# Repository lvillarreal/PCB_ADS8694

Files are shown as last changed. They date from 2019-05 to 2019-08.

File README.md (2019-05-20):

# PCB PARA ADS8694

## Características del PCB

 - 4 entradas diferenciales con acondiconamiento (AD8221)
 - Entrada canal 0 sin filtro RC
 - Entradas canales 1-3 con filtro RC, LP 
 - Salida compatible con Pmod (6x6, 2.54mm, 90º) de Xilinx
 - Uso de referencia interna de AD

## Características ADS8694

 - 18 bits
 - 500 kSPS
 - Filtro Pasa bajos incorporado internamente, fc=15 kHz (Oversampling)
 - Interface SPI
 - Pin de alarma
 - Impedancia de entrada: 1MΩ
 - Encapsulado TSSOP (38)
 - Conversión SAR (aproximaciones sucesivas)

### Diagrama en bloques

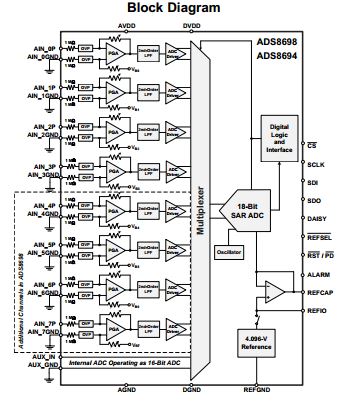
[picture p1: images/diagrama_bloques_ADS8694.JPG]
Diagrama en bloques


### Pines

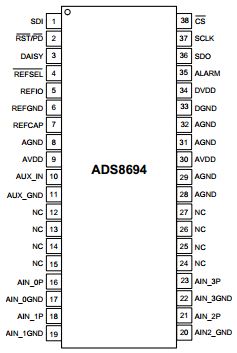
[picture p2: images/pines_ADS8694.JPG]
Pinout


### Definicion de Pines

| Nº | Nombre | I/O | Descripción |
| -- | -----| --- | --- |
| 1  | SDI  |Entrada Digital | Data in |
| 2  | /RST-/PD | Entrada Digital  | Reset y Power Down |
| 3  | DAISY  | Entrada Digital | Modo Daisy-Chain |
| 4  | /REFSEL  |Entrada Digital  | Entrada lógica activa por bajo para habilitar la referencia interna. Cuando está en bajo, la referencia interna está habilitada.  REFIO se convierte en una salida que incluye la referencia de tensión V_REF. Cuando REFSEL está en alto la ref interna está deshabilitada y REFIO se convierte en la referencia (entrada analógica)|
| 5  | REFIO  | Entrada/Salida Analógica  | Se explica arriba |
| 6  | REFGND  | Power Supply | Pin de GND analógica, corto al plano analógico GND. Desacoplar con REFIO en el pin 5 y REFCAP en el pin 7 |
| 7  | REFCAP  | Salida Analógica | Pin de condensador de desacoplamiento de referencia ADC. Desacoplar con REFGND en el pin 6 |
| 8 |  AGND | Power Supply | Pin de tierra analógica. Desacoplar con AVDD en pin 9 |
| 9  |  AVDD |  Power Supply  | Pin suministro analógico. Desacoplar con AGND pin 8|
| 10 | AUX_IN | Entrada Analógica | Canal de entrada auxiliar: entrada positiva. Desacoplar con pin 11, AUX_GND |
| 11 | AUX_GND | Entrada Analógica | Canal de entrada auxiliar: entrada negativa. Desacoplar con pin 10, AUX_IN |
|16|AIN_0P| Entrada analógica |Canal de entrada analógica 0, entrada positiva. Desacoplar con AIN_0GND en el pin 17|
|17| AIN_0GND| Entrada analógica| Canal de entrada analógica 0, entrada negativa. Desacoplar con AIN_0P en el pin 16|
| 18 | AIN_1P | Entrada analógica |  |
| 19 |AIN_1GND | Entrada analógica |  |
| 20 | AIN_2GND | Entrada analógica |  |
| 21 | AIN_2P | Entrada analógica |  |
| 22 | AIN_3GND | Entrada analógica |  |
| 23 | AIN_3P | Entrada analógica |  |
|28| AGND| Power Supply| Toma de tierra analógica|
|29| AGND| Power Supply| Toma de tierra analógica|
|30| AVDD| Power Supply| Fuente de alimentación analógica. Desacoplar con AGND
|31| AGND| Power Supply| Toma de tierra analógica|
|32| AGND| Power Supply|
|33| DGND | Power Supply | Desacoplar con 35, DVDD|
|34| AVDD | Power Supply | Desacoplar con 34, AGND|
|35|ALARM| Salida Digital |Salida de alarma activa por alto|
|36|SDO| Salida Digital | Dato de salida, SPI|
|37|SCL| Entrada Digital | clock SPI |
|38|/CS| Entrada digital | Chip Slect SPI, activo por bajo|

### Entrada Analógica

El rango de tensión de entrada se puede configurar para ±2.5 Vref, ±1.25 Vref ; ±0.625 Vref (bipolar) o 0 a 2.5 Vref, 0 a 1.25 Vref (unipolar). La configuración es independiente para cada canal (4 canales).
El dispositivo muestrea la diferencia entre AIN_nP y AIN_nGND, donde el valor máximo que puede tomar AIN_nGND es ±0.1 V.

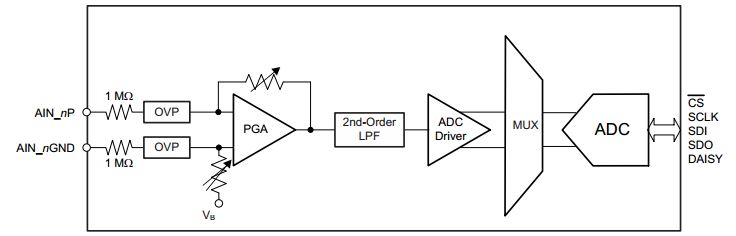
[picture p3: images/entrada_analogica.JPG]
Entrada_Analógica


### Programmable Gain Amplifier (PGA)

Dependiendo del rango de la señal de entada, se puede ajustar la ganancia modificando los bits Range_CHn [3:0] en el registro de programa.El valor predeterminado es 0000, que corresponde a un rango de señal de entrada de ± 2.5 × Vref.

| Rango de entrada analógica | Bit 3 | Bit 2 | Bit 1 | Bit 0 |
|---|---|---|---|---|
| ±2.5 x Vref | 0 | 0 | 0 | 0 |
| ±1.25 x Vref | 0 | 0 | 0 | 1 |
| ±0.625 x Vref | 0 | 0 | 1 | 0 |
|0 a 2.5 x Vref | 0 | 1 | 0 | 1 |
|0 a 1.25 x Vref | 0 | 1 | 1 | 0 |

### Multiplexor

Dispone de un mux analógico de 4 canales. Puede funcionar en modo manual o de escaneo automático.En modo manual (MAN_Ch_n), el canal se selecciona para cada muestra a través de un registro de escritura; en modo de escaneo automático (AUTO_RST), el número de canal se incrementa automáticamente en cada flanco descendente de /CS después de muestrear el canal actual.
Las entradas analógicas pueden ser seleccionadas por un scaneo automático configurando los registros pertinente. El dispositivo escanea solo las entradas analógicas seleccionadas en orden ascendente. El rendimiento total es de 500kSPS, pero se divide entre los canales activos. Si hay uno solo activo, será de 500 kSPS; si hay 2 será de 250kSPS por canal; etc.

### Referencia interna
Circuito recomendado

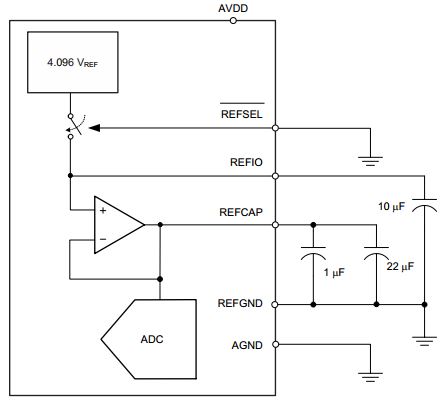
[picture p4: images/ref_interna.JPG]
Referencia interna


### Modos de funcionamiento
El ADS8694 admite múltiples modos de operación que son programables por software. Después de encendido, el dispositivo se coloca en modo inactivo y no realiza ninguna función hasta que se recibe un comando del usuario. Más adelante se enumeran en una tabla todos los comandos para ingresar a los diferentes modos del dispositivo. Después del encendido, los registros de programa se activan con los valores predeterminados y requieren ajustes de configuración apropiados antes de realizar cualquier conversión. El siguiente diagrama explica cómo cambiar el dispositivo de un modo de operación a otro.

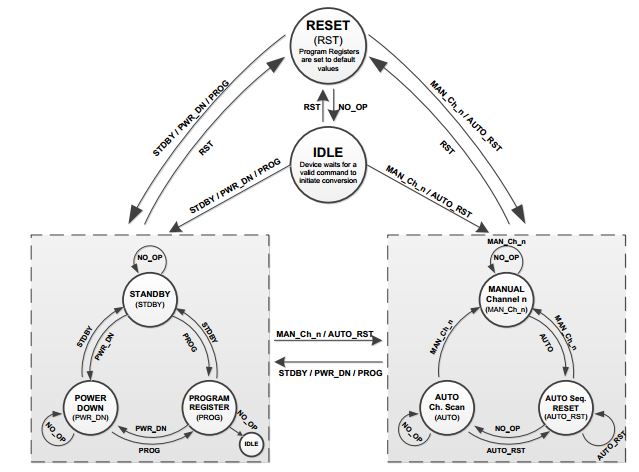
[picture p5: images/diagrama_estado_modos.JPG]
Modos de operacion


### Valores de LSB para Vref de 4.096 V

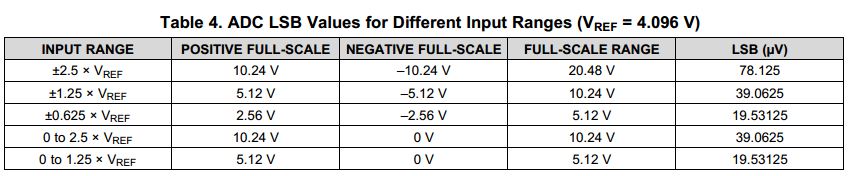
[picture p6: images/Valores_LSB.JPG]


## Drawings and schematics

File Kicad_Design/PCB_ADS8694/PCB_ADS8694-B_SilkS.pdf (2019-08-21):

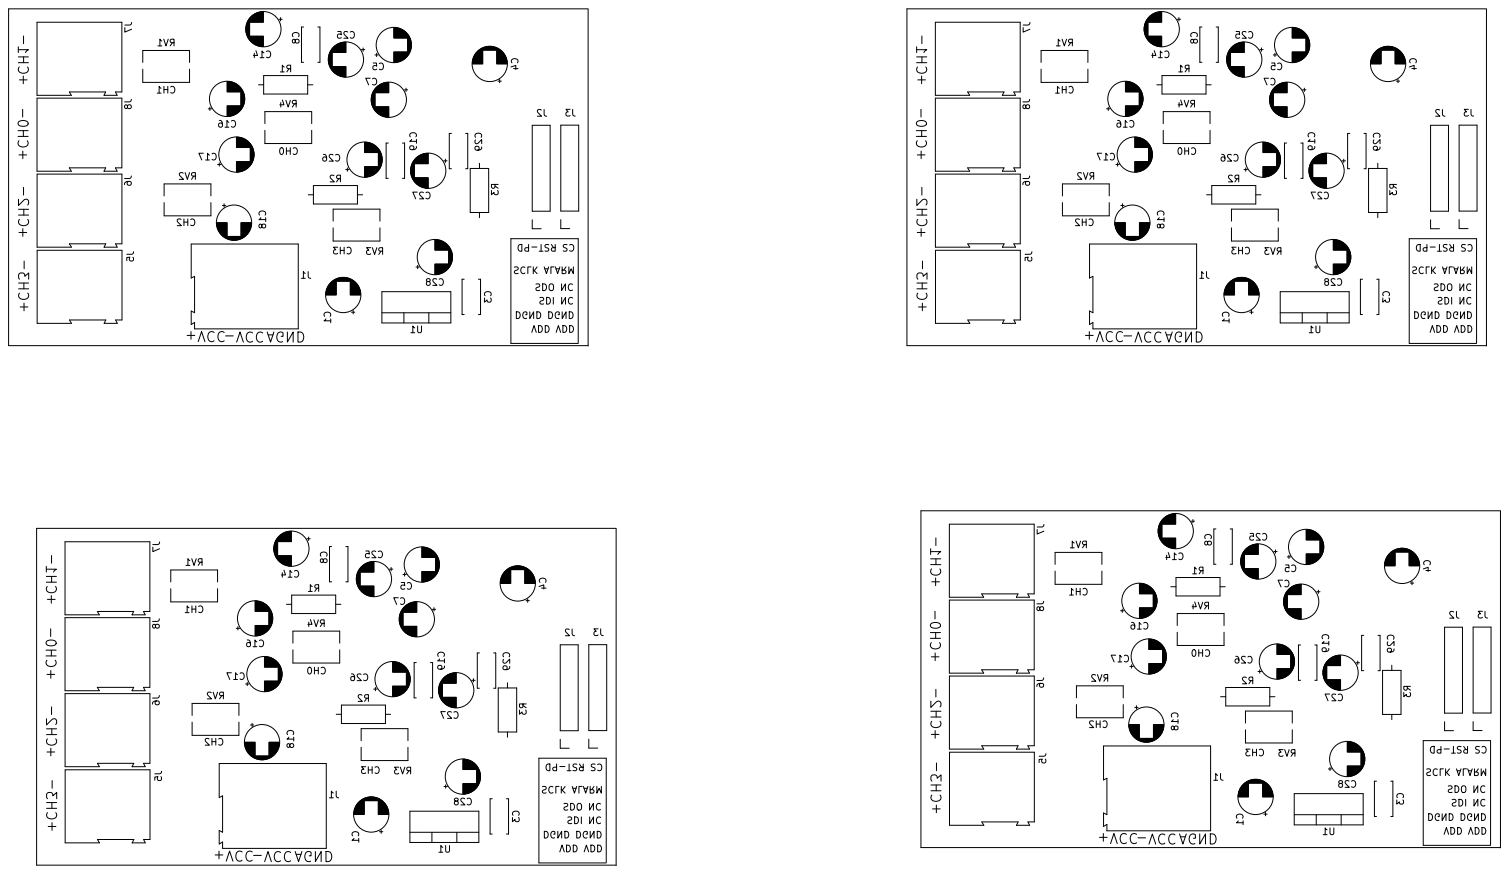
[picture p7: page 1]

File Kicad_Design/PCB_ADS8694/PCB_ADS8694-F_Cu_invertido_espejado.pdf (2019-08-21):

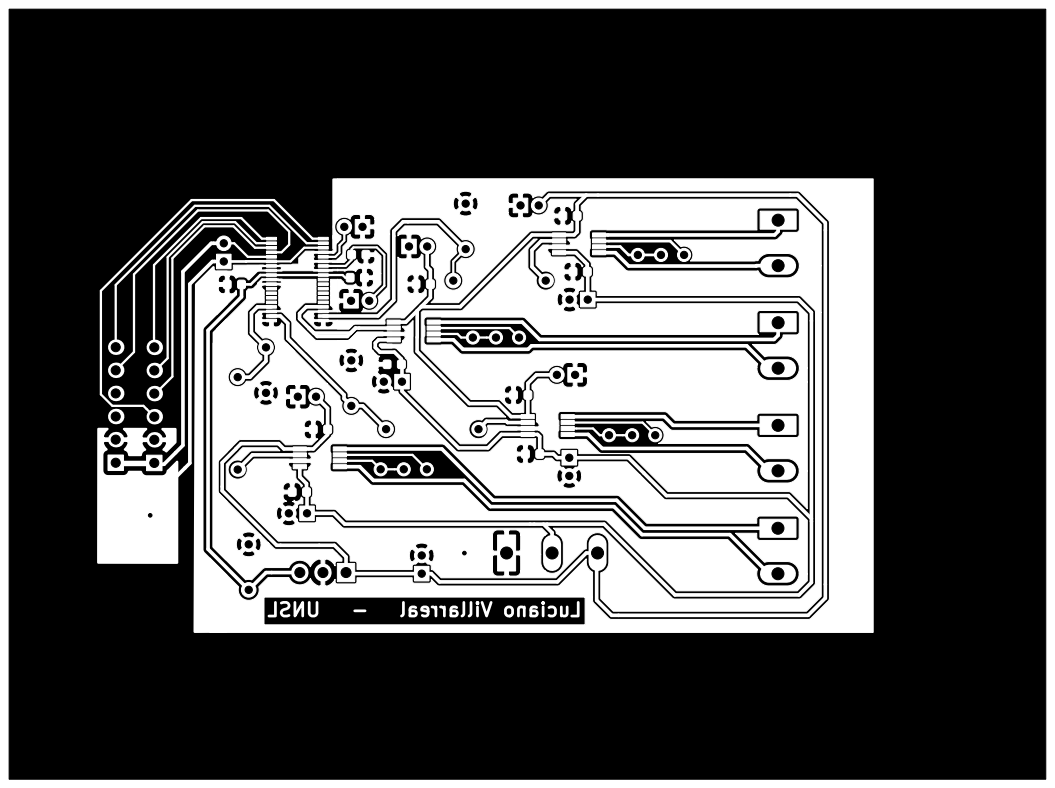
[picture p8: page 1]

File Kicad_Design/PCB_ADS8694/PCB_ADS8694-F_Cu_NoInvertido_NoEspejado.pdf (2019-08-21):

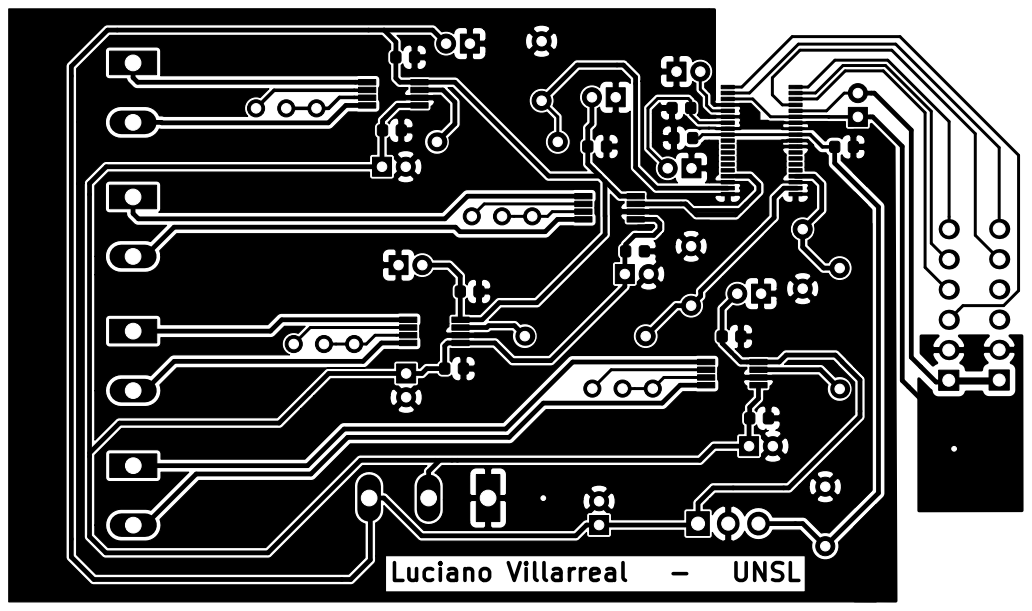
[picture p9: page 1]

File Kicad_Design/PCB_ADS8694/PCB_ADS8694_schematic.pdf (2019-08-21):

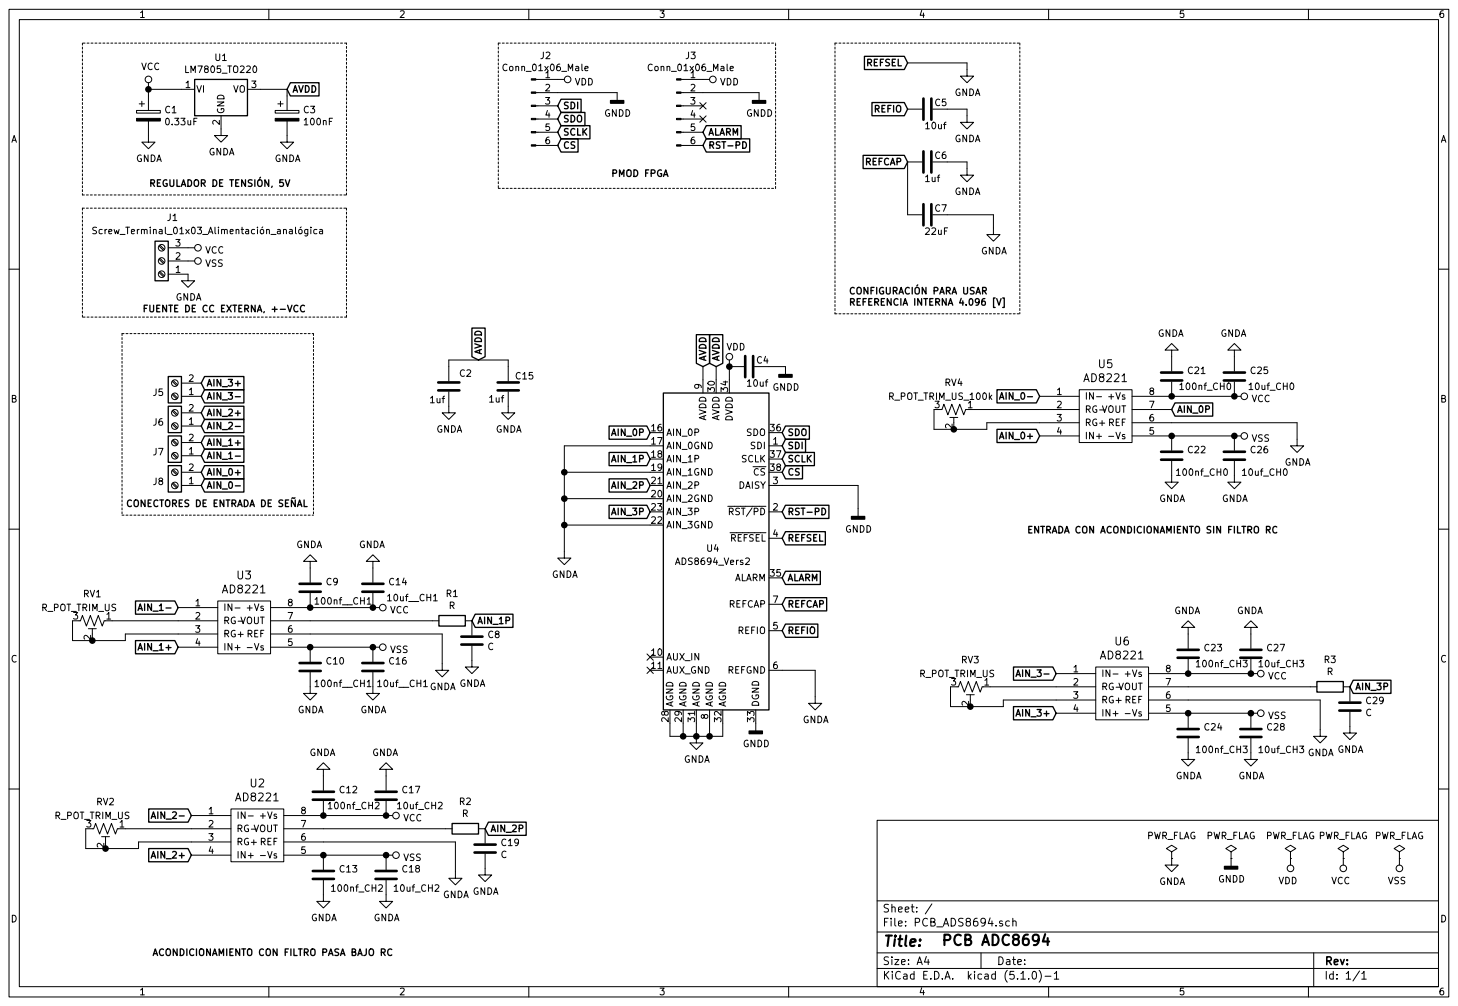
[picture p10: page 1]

REFERENCIA INTERNA 4.096 [V] PMOD FPGA

REFCAP CONFIGURACIÓN PARA USAR

ENTRADA CON ACONDICIONAMIENTO SIN FILTRO RC

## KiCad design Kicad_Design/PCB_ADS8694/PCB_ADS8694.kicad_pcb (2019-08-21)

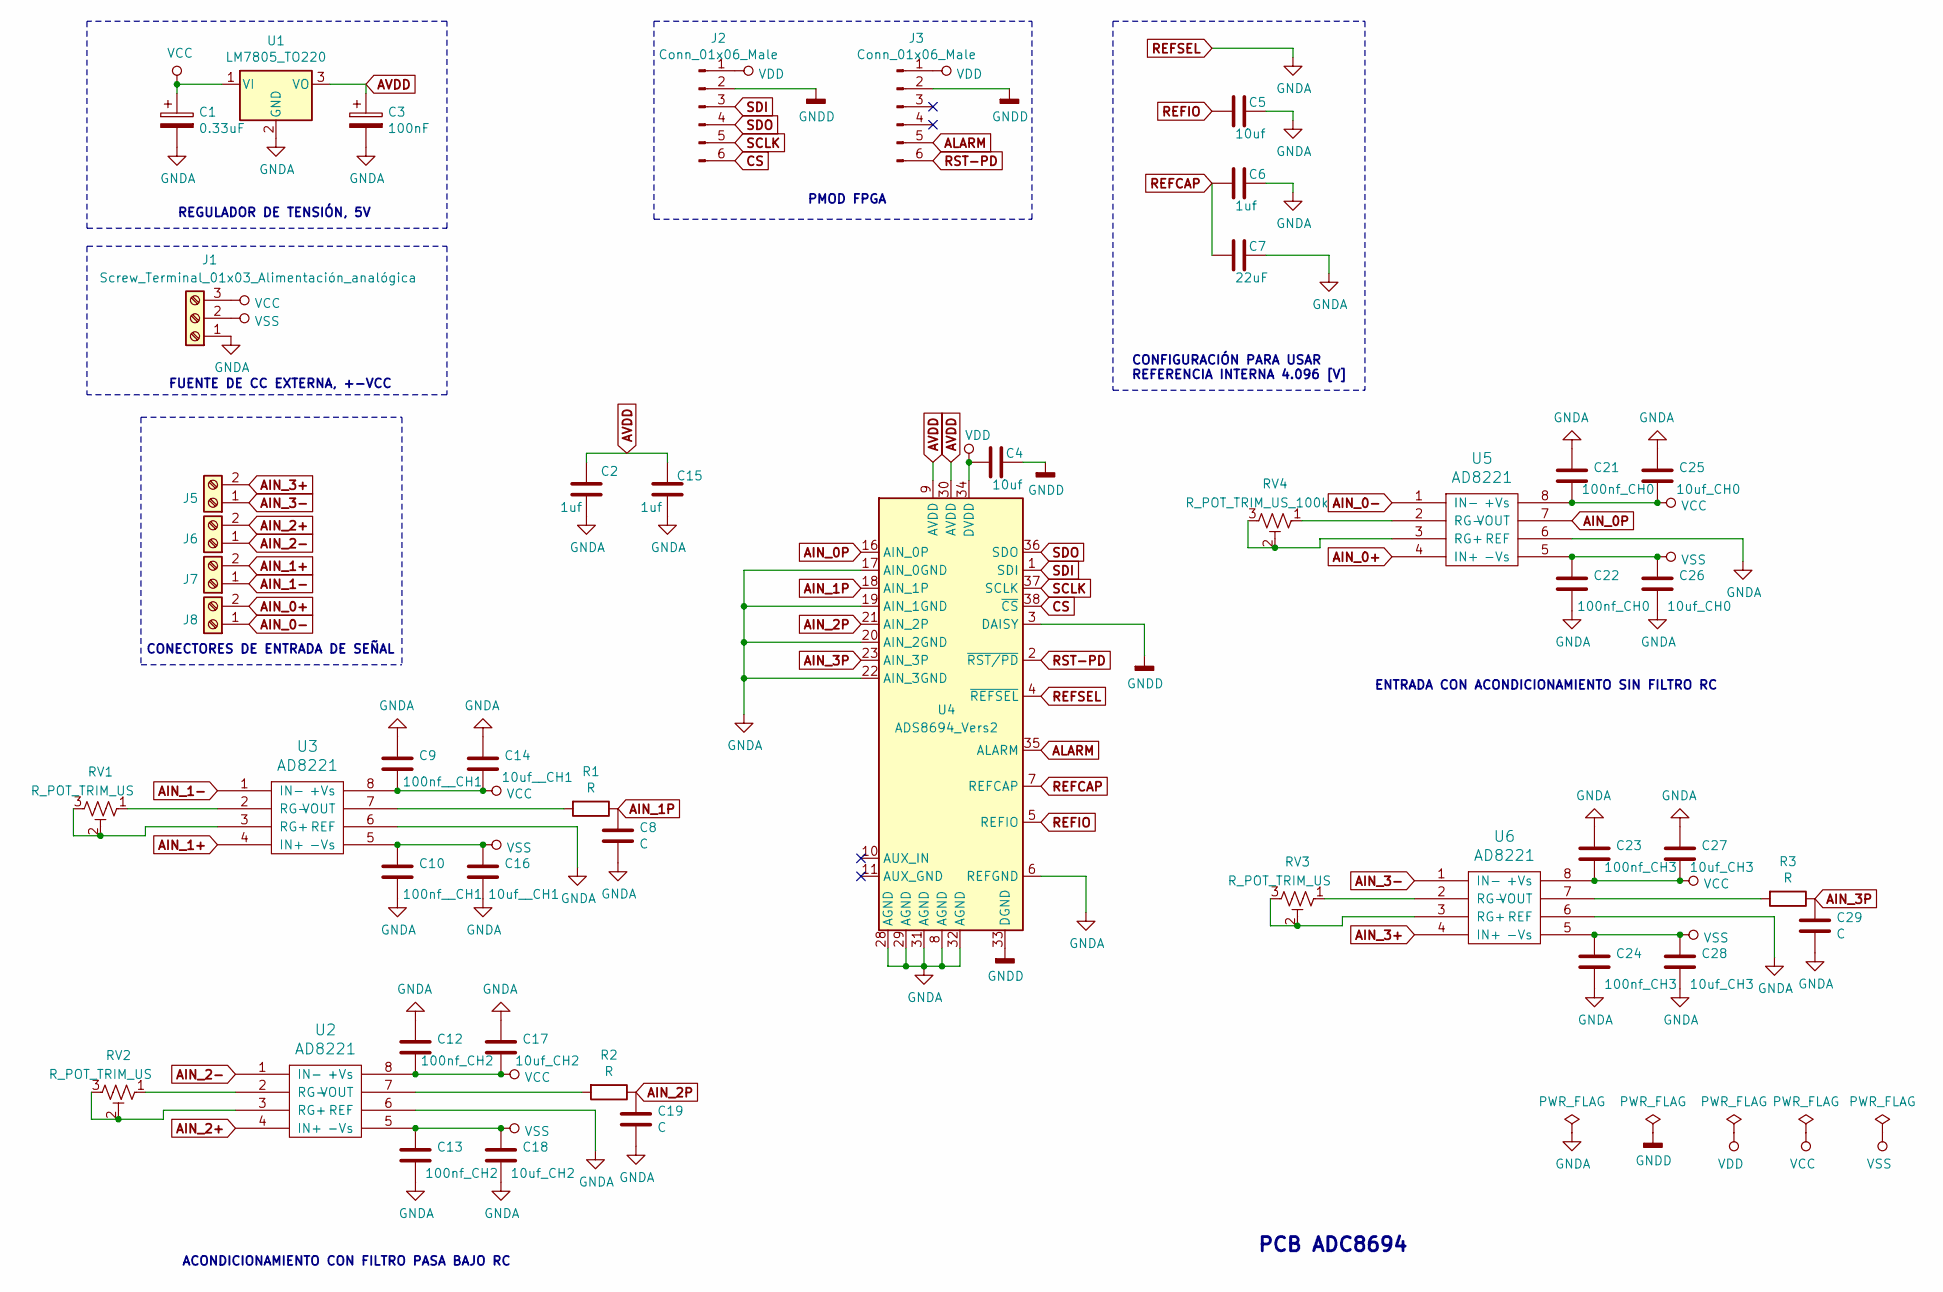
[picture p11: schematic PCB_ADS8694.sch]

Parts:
C1: 0.33uF; CP_Radial_D5.0mm_P2.00mm
C2, C6, C15: 1uf; C_0603_1608Metric
C3: 100nF; C_Disc_D5.0mm_W2.5mm_P5.00mm
C4, C5: 10uf; CP_Radial_D5.0mm_P2.00mm
C7: 22uF; CP_Radial_D5.0mm_P2.00mm
C8, C19, C29: C; C_Disc_D5.0mm_W2.5mm_P5.00mm
C9, C10: 100nf__CH1; C_0603_1608Metric
C12, C13: 100nf_CH2; C_0603_1608Metric
C14, C16: 10uf__CH1; CP_Radial_D5.0mm_P2.00mm
C17, C18: 10uf_CH2; CP_Radial_D5.0mm_P2.00mm
C21, C22: 100nf_CH0; C_0603_1608Metric
C23, C24: 100nf_CH3; C_0603_1608Metric
C25, C26: 10uf_CH0; CP_Radial_D5.0mm_P2.00mm
C27, C28: 10uf_CH3; CP_Radial_D5.0mm_P2.00mm
J1: Screw_Terminal_01x03_Alimentación_analógica; TerminalBlock_Altech_AK300-3_P5.00mm
J2, J3: Conn_01x06_Male; PinHeader_1x06_P2.54mm_Vertical
J5: Screw_Terminal_01x02_CH3; TerminalBlock_Altech_AK300-2_P5.00mm
J6: Screw_Terminal_01x02_CH2; TerminalBlock_Altech_AK300-2_P5.00mm
J7: Screw_Terminal_01x02_CH1; TerminalBlock_Altech_AK300-2_P5.00mm
J8: Screw_Terminal_01x02_CH0; TerminalBlock_Altech_AK300-2_P5.00mm
R1, R2, R3: R; R_Axial_DIN0207_L6.3mm_D2.5mm_P10.16mm_Horizontal
RV1, RV2, RV3: R_POT_TRIM_US; Potentiometer_Bourns_3266Y_Vertical
RV4: R_POT_TRIM_US_100k; Potentiometer_Bourns_3266Y_Vertical
U1: LM7805_TO220; TO-220-3_Vertical
U2, U3, U5, U6: AD8221; MSOP-8_3x3mm_P0.65mm
U4: ADS8694_Vers2; TSSOP-38_4.4x9.7mm_P0.5mm

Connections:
AIN_0+: J8.2, U5.4 (IN+)
AIN_0-: J8.1, U5.1 (IN-)
AIN_0P: U4.16 (AIN_0P), U5.7 (VOUT)
AIN_1+: J7.2, U3.4 (IN+)
AIN_1-: J7.1, U3.1 (IN-)
AIN_1P: C8.1, R1.1, U4.18 (AIN_1P)
AIN_2+: J6.2, U2.4 (IN+)
AIN_2-: J6.1, U2.1 (IN-)
AIN_2P: C19.1, R2.1, U4.21 (AIN_2P)
AIN_3+: J5.2, U6.4 (IN+)
AIN_3-: J5.1, U6.1 (IN-)
AIN_3P: C29.1, R3.1, U4.23 (AIN_3P)
ALARM: J3.5, U4.35 (ALARM)
AVDD: C2.1, C3.1, C15.2, U1.3 (VO), U4.9 (AVDD), U4.30 (AVDD)
CS: J2.6, U4.38 (~CS)
GNDD: C4.1, J2.2, J3.2, U4.3 (DAISY), U4.33 (DGND)
unnamed: R1.2, U3.7 (VOUT)
unnamed: R2.2, U2.7 (VOUT)
unnamed: R3.2, U6.7 (VOUT)
unnamed: RV1.1, U3.2 (RG-)
unnamed: RV1.2, RV1.3, U3.3 (RG+)
unnamed: RV2.1, U2.2 (RG-)
unnamed: RV2.2, RV2.3, U2.3 (RG+)
unnamed: RV3.1, U6.2 (RG-)
unnamed: RV3.2, RV3.3, U6.3 (RG+)
unnamed: RV4.1, U5.2 (RG-)
unnamed: RV4.2, RV4.3, U5.3 (RG+)
REFCAP: C6.2, C7.2, U4.7 (REFCAP)
REFIO: C5.2, U4.5 (REFIO)
REFSEL: C1.2, C2.2, C3.2, C5.1, C6.1, C7.1, C8.2, C9.1, C10.2, C12.1, C13.2, C14.1, C15.1, C16.2, C17.1, C18.2, C19.2, C21.1, C22.2, C23.1, C24.2, C25.1, C26.2, C27.1, C28.2, C29.2, J1.1, U1.2 (GND), U2.6 (REF), U3.6 (REF), U4.4 (~REFSEL), U4.6 (REFGND), U4.8 (AGND), U4.17 (AIN_0GND), U4.19 (AIN_1GND), U4.20 (AIN_2GND), U4.22 (AIN_3GND), U4.28 (AGND), U4.29 (AGND), U4.31 (AGND), U4.32 (AGND), U5.6 (REF), U6.6 (REF)
RST-PD: J3.6, U4.2 (~RST/PD)
SCLK: J2.5, U4.37 (SCLK)
SDI: J2.3, U4.1 (SDI)
SDO: J2.4, U4.36 (SDO)
VCC: C1.1, C9.2, C12.2, C14.2, C17.2, C21.2, C23.2, C25.2, C27.2, J1.3, U1.1 (VI), U2.8 (+Vs), U3.8 (+Vs), U5.8 (+Vs), U6.8 (+Vs)
VDD: C4.2, J2.1, J3.1, U4.34 (DVDD)
VSS: C10.1, C13.1, C16.1, C18.1, C22.1, C24.1, C26.1, C28.1, J1.2, U2.5 (-Vs), U3.5 (-Vs), U5.5 (-Vs), U6.5 (-Vs)

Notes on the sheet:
CONFIGURACIÓN PARA USAR REFERENCIA INTERNA 4.096 [V]
PMOD FPGA
REGULADOR DE TENSIÓN, 5V
PCB ADC8694
FUENTE DE CC EXTERNA, +-VCC
ENTRADA CON ACONDICIONAMIENTO SIN FILTRO RC
CONECTORES DE ENTRADA DE SEÑAL
ACONDICIONAMIENTO CON FILTRO PASA BAJO RC

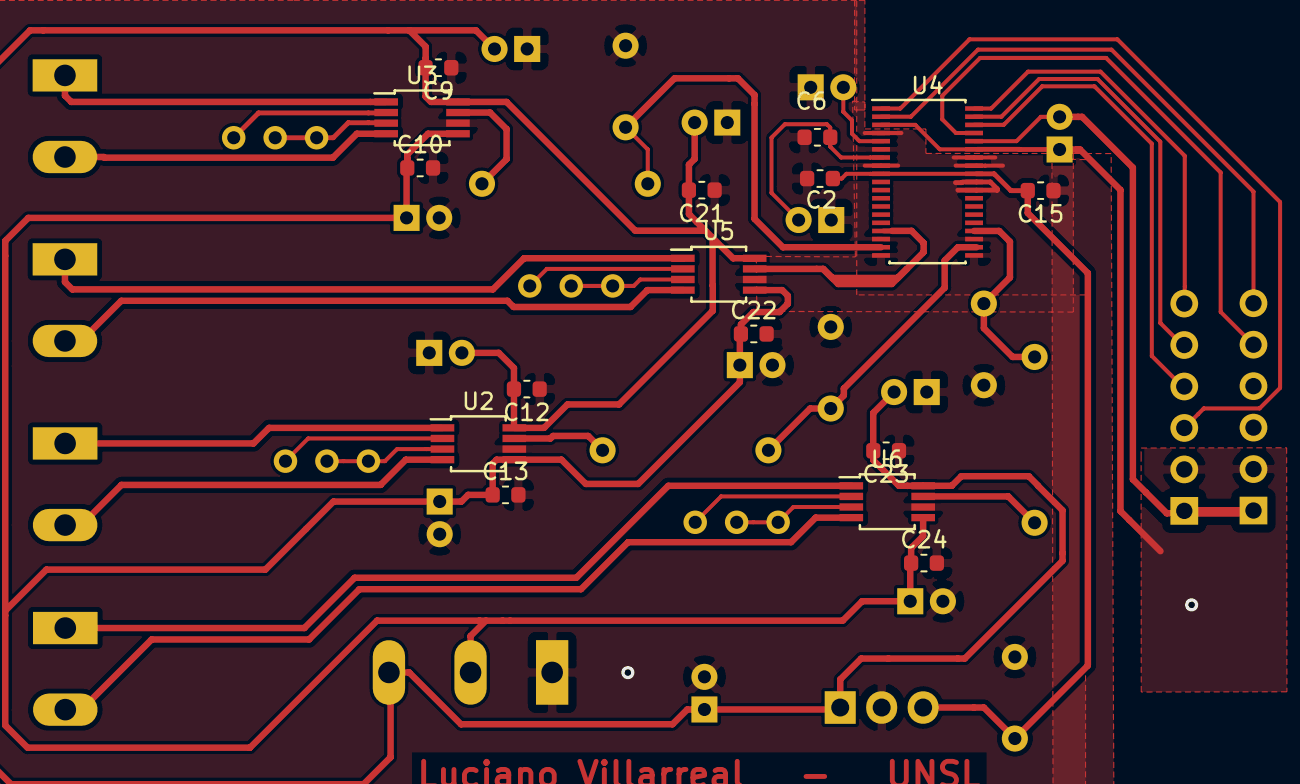
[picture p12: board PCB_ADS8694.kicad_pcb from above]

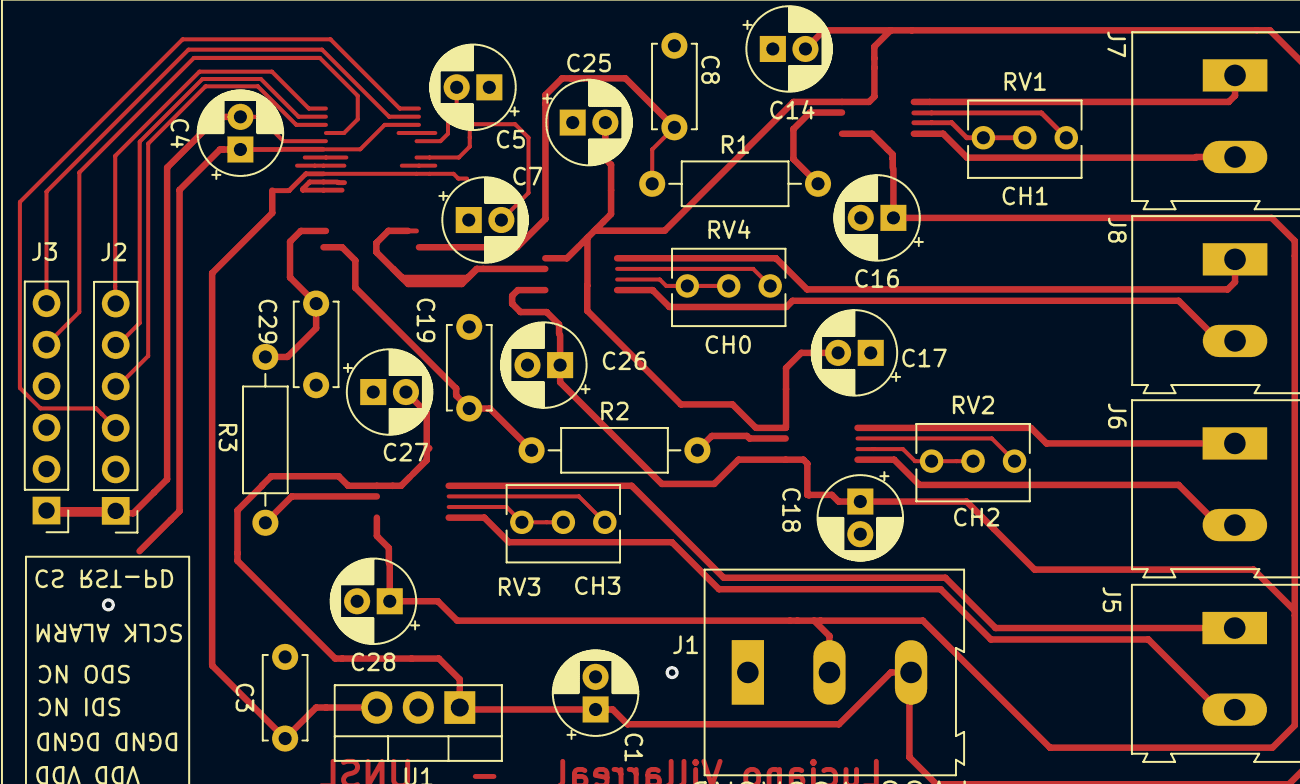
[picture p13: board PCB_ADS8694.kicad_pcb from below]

Board: 2 copper layers, 47 parts (31 on the bottom side), 37 nets.

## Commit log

2019-04-30 Se crea simbolo de ADS8694
    [PCB_ADS8694.kicad_pcb, PCB_ADS8694.sch]
2019-05-02 Edición de readme.m
2019-05-02 Se crea circuito ded referencia interna, pmod y circuito de tension de alimentación analógica
    [PCB_ADS8694.kicad_pcb, PCB_ADS8694.sch]
2019-05-03 Se agrega circuito de seleccion modo daisy-chain
    [PCB_ADS8694.sch]
2019-05-07 Agregado de info en README
2019-05-07 Se agrega acondicionamiento, entradas analogicas, cambios varios
    [PCB_ADS8694.sch]
2019-05-08 Se agregan AD8221 en los 4 canales
    [PCB_ADS8694.sch]
2019-05-11 Se agrega AD8221 en 4 canales, se agrega pin para daisy chain
    [PCB_ADS8694.sch]
2019-05-11 Se agrega informacion, primer version terminada
    [PCB_ADS8694.sch]
2019-05-12 cambios de alimentación
    [PCB_ADS8694.sch]
2019-05-13 Agregado de capacitor para filtrar componente de CC en canal 0
    [PCB_ADS8694.sch]
2019-05-13 Asignacion de huellas
    [PCB_ADS8694.sch]
2019-05-14 agregado de capacitores de desacoplo
    [PCB_ADS8694.sch]
2019-05-15 Agregado de capacitores de desacople, cambios en simbolo de AD
    [PCB_ADS8694.sch]
2019-05-15 Creacion de listado de redes
2019-05-15 Modificacion simbolo AD, agregado de capacitores de desacople, asignacion de huellas
    [PCB_ADS8694.sch]
2019-05-18 se elimina canal aux, se elimina jumper daisy
    [PCB_ADS8694.sch]
2019-05-18 PCB creado, V1
    [PCB_ADS8694.kicad_pcb]
2019-05-18 lista de redes
2019-05-19 Cambios en encapsulados. Agregado de serigrafía
    [PCB_ADS8694.kicad_pcb, PCB_ADS8694.sch]
2019-05-19 cambios varios, reduccion de tamaño
    [PCB_ADS8694.kicad_pcb]
2019-05-19 Cambio en ancho de pistas
    [PCB_ADS8694.kicad_pcb]
2019-05-19 Agregado de cotas
    [PCB_ADS8694.kicad_pcb]
2019-05-20 PCB V1
    [PCB_ADS8694.kicad_pcb, PCB_ADS8694.sch]
2019-05-24 Se cambia orientacion de bornera +-12V, con esto se evita usar vias para unir plano agnd. Se agregan vias para unir agnd con dgnd
    [PCB_ADS8694.kicad_pcb, PCB_ADS8694.sch]
2019-05-24 Se agranda el ancho de pista canal 0, para efectauar mediciones con mayor facilidad
    [PCB_ADS8694.kicad_pcb]
2019-05-24 union agnd dgnd
    [PCB_ADS8694.sch]
2019-06-02 Cambios en conector pmod
    [PCB_ADS8694.kicad_pcb, PCB_ADS8694.sch]
2019-06-03 Capacitores 10uF de smd a THT
    [PCB_ADS8694.kicad_pcb, PCB_ADS8694.sch]
2019-06-07 Cambios varios, Version 1 funcional
    [PCB_ADS8694.kicad_pcb, PCB_ADS8694.sch]
2019-06-10 Capa de cobre invertida
2019-08-21 version finalizada
    [PCB_ADS8694.kicad_pcb, PCB_ADS8694.sch]
